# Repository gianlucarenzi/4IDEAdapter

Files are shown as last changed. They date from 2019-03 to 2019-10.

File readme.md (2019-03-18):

# Amiga 4 IDE Hard Parallel ATA Adapter
Created by Gianluca Renzi (C) 2019
E-Mail: <icjtqr@gmail.com>
<gianlucarenzi@eurek.it>

# What is it?
It is a simple but powerful adapter to use internally in any Amiga 1200 or Amiga 600 Computer installed in a tower-like case!
It must be connected to the IDE 44-pin interface on the motherboard to drive up to 4 ATA/ATAPI devices like Hard Drives, DVD Rom Drives and compatible drives.

This project follow the same DIY project in Aminet (search 4IDE in docs/hw) or simply check out here:

[Aminet 4IDE Readme](Aminet-4IDE/4IDE.readme)

# Software
[Aminet IDE97 Driver](http://aminet.net/driver/media/IDEfix97.lha)

[Aminet IDE97 Turbo Driver](http://aminet.net/driver/media/IDEfixTURBO.lha)

[Aminet IDE97 Patches](http://aminet.net/driver/media/IDEFix_patches.lha)

# Hardware Point-Of-View
This board has three indipendent activity leds, one for each channel. Moreover the activity leds are merged together in the motherboard so the HDD led nearby the floppy connector can be used as the only activity led.

# TODO
May be it can be useful to add a 90-degrees rise connector if the system has some sort of bus board, just to let this board flat as the motherboard.

# Images
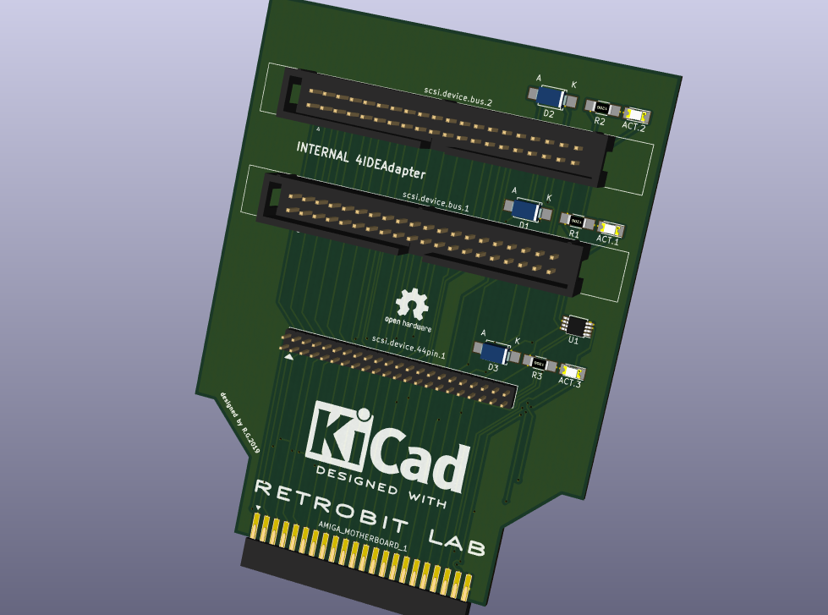
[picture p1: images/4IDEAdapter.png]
Board Overall

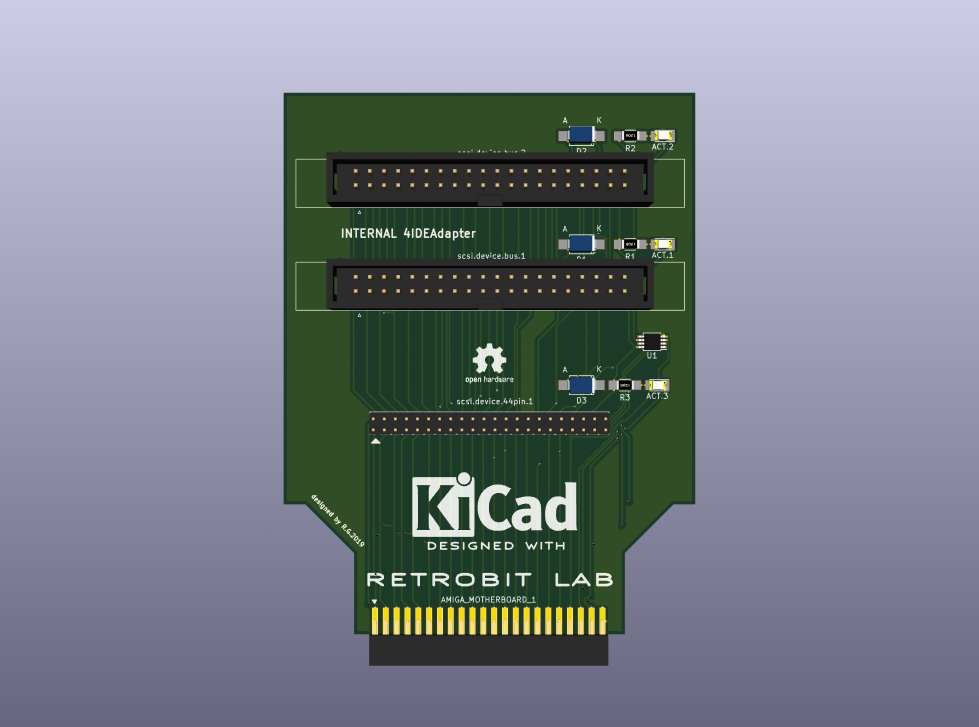
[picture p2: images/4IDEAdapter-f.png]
Board Front

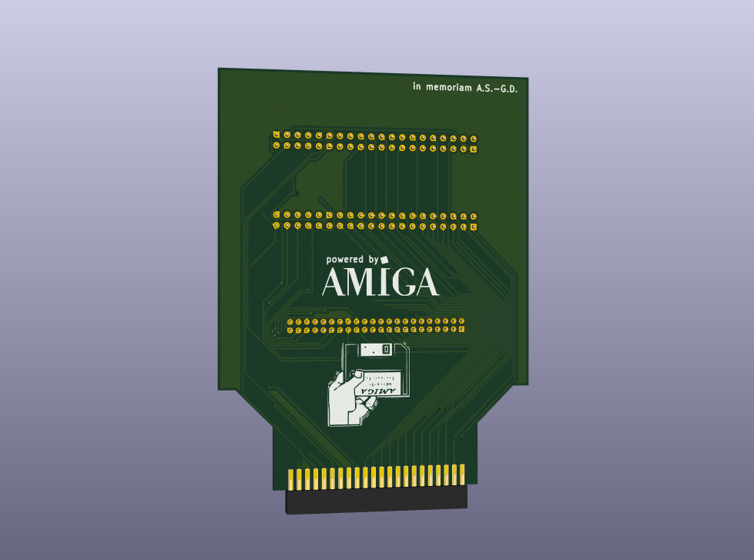
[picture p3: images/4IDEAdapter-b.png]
Board Back


# Whats changed?
V2.2 Added Aminet Stuff

# Licence
This entire project is available under the GNU General Public License v3 licence.
See licence.txt for more details.

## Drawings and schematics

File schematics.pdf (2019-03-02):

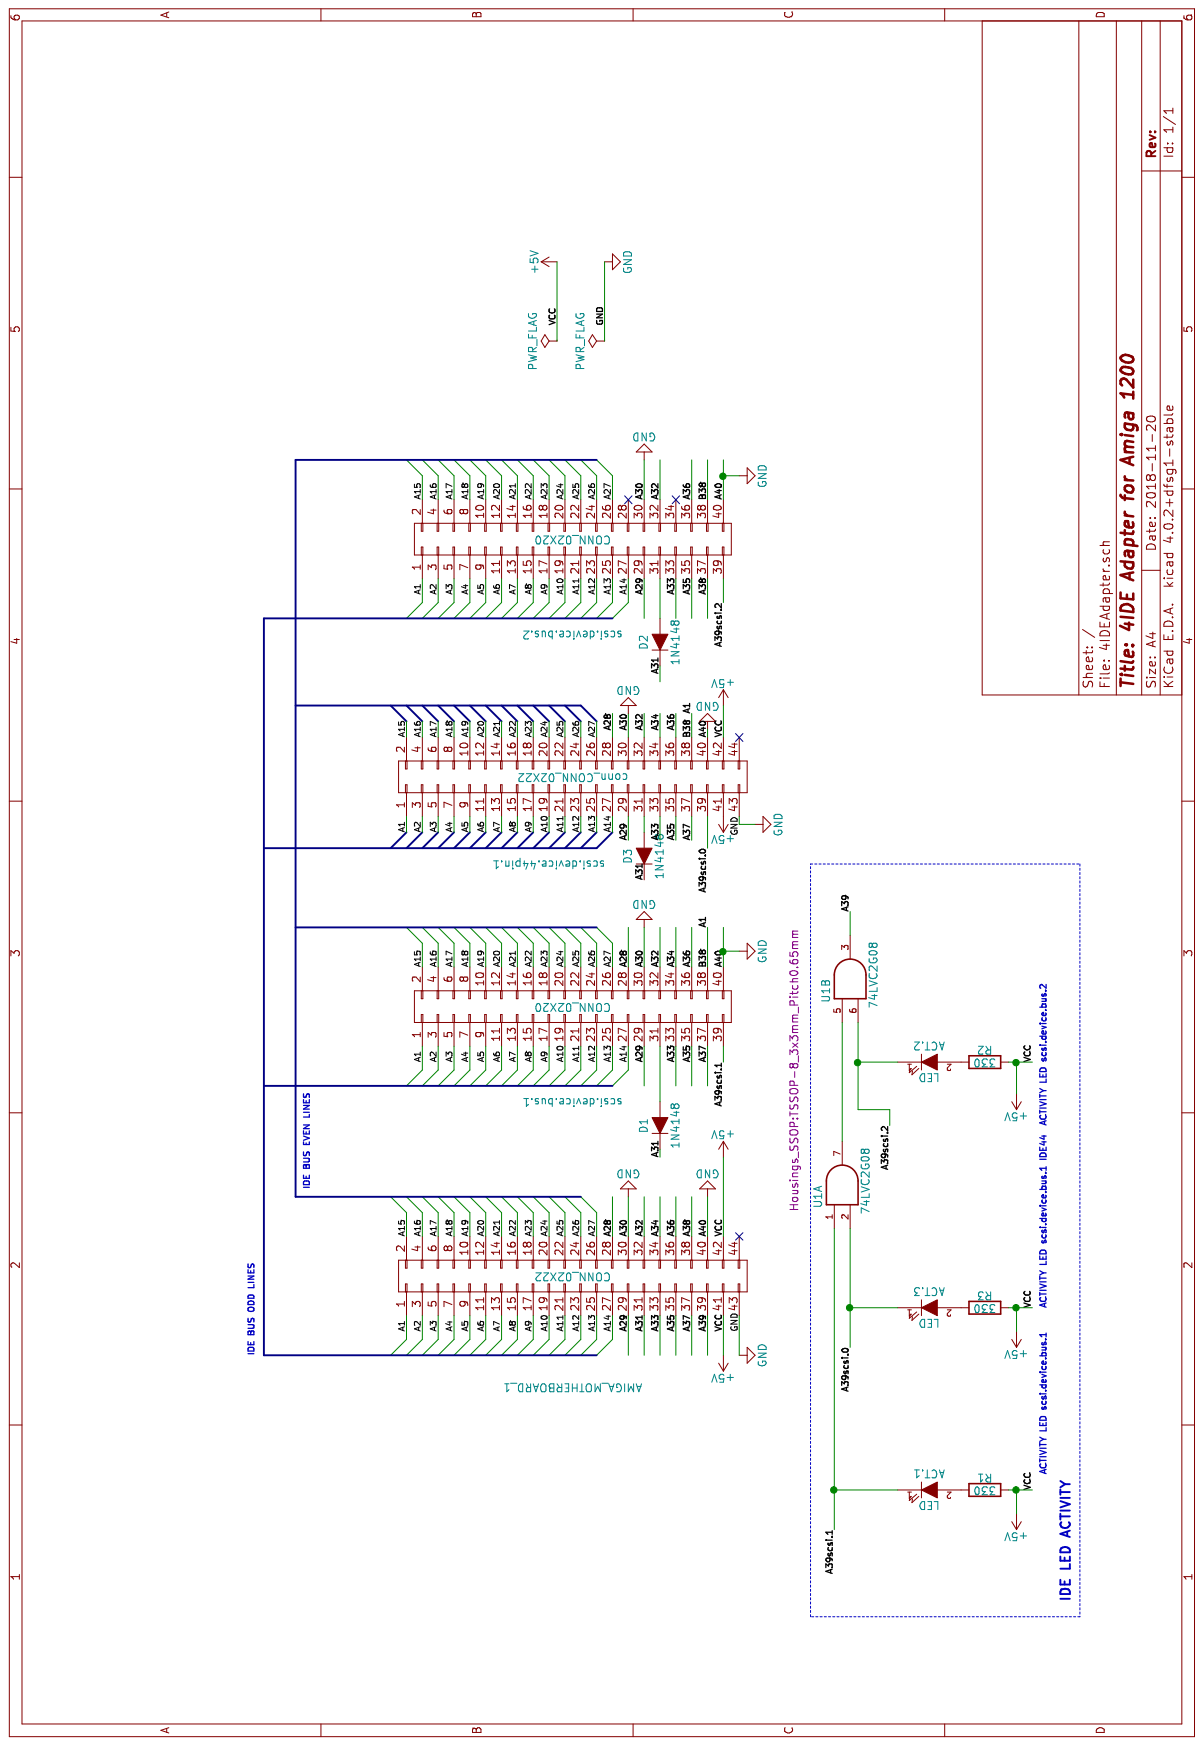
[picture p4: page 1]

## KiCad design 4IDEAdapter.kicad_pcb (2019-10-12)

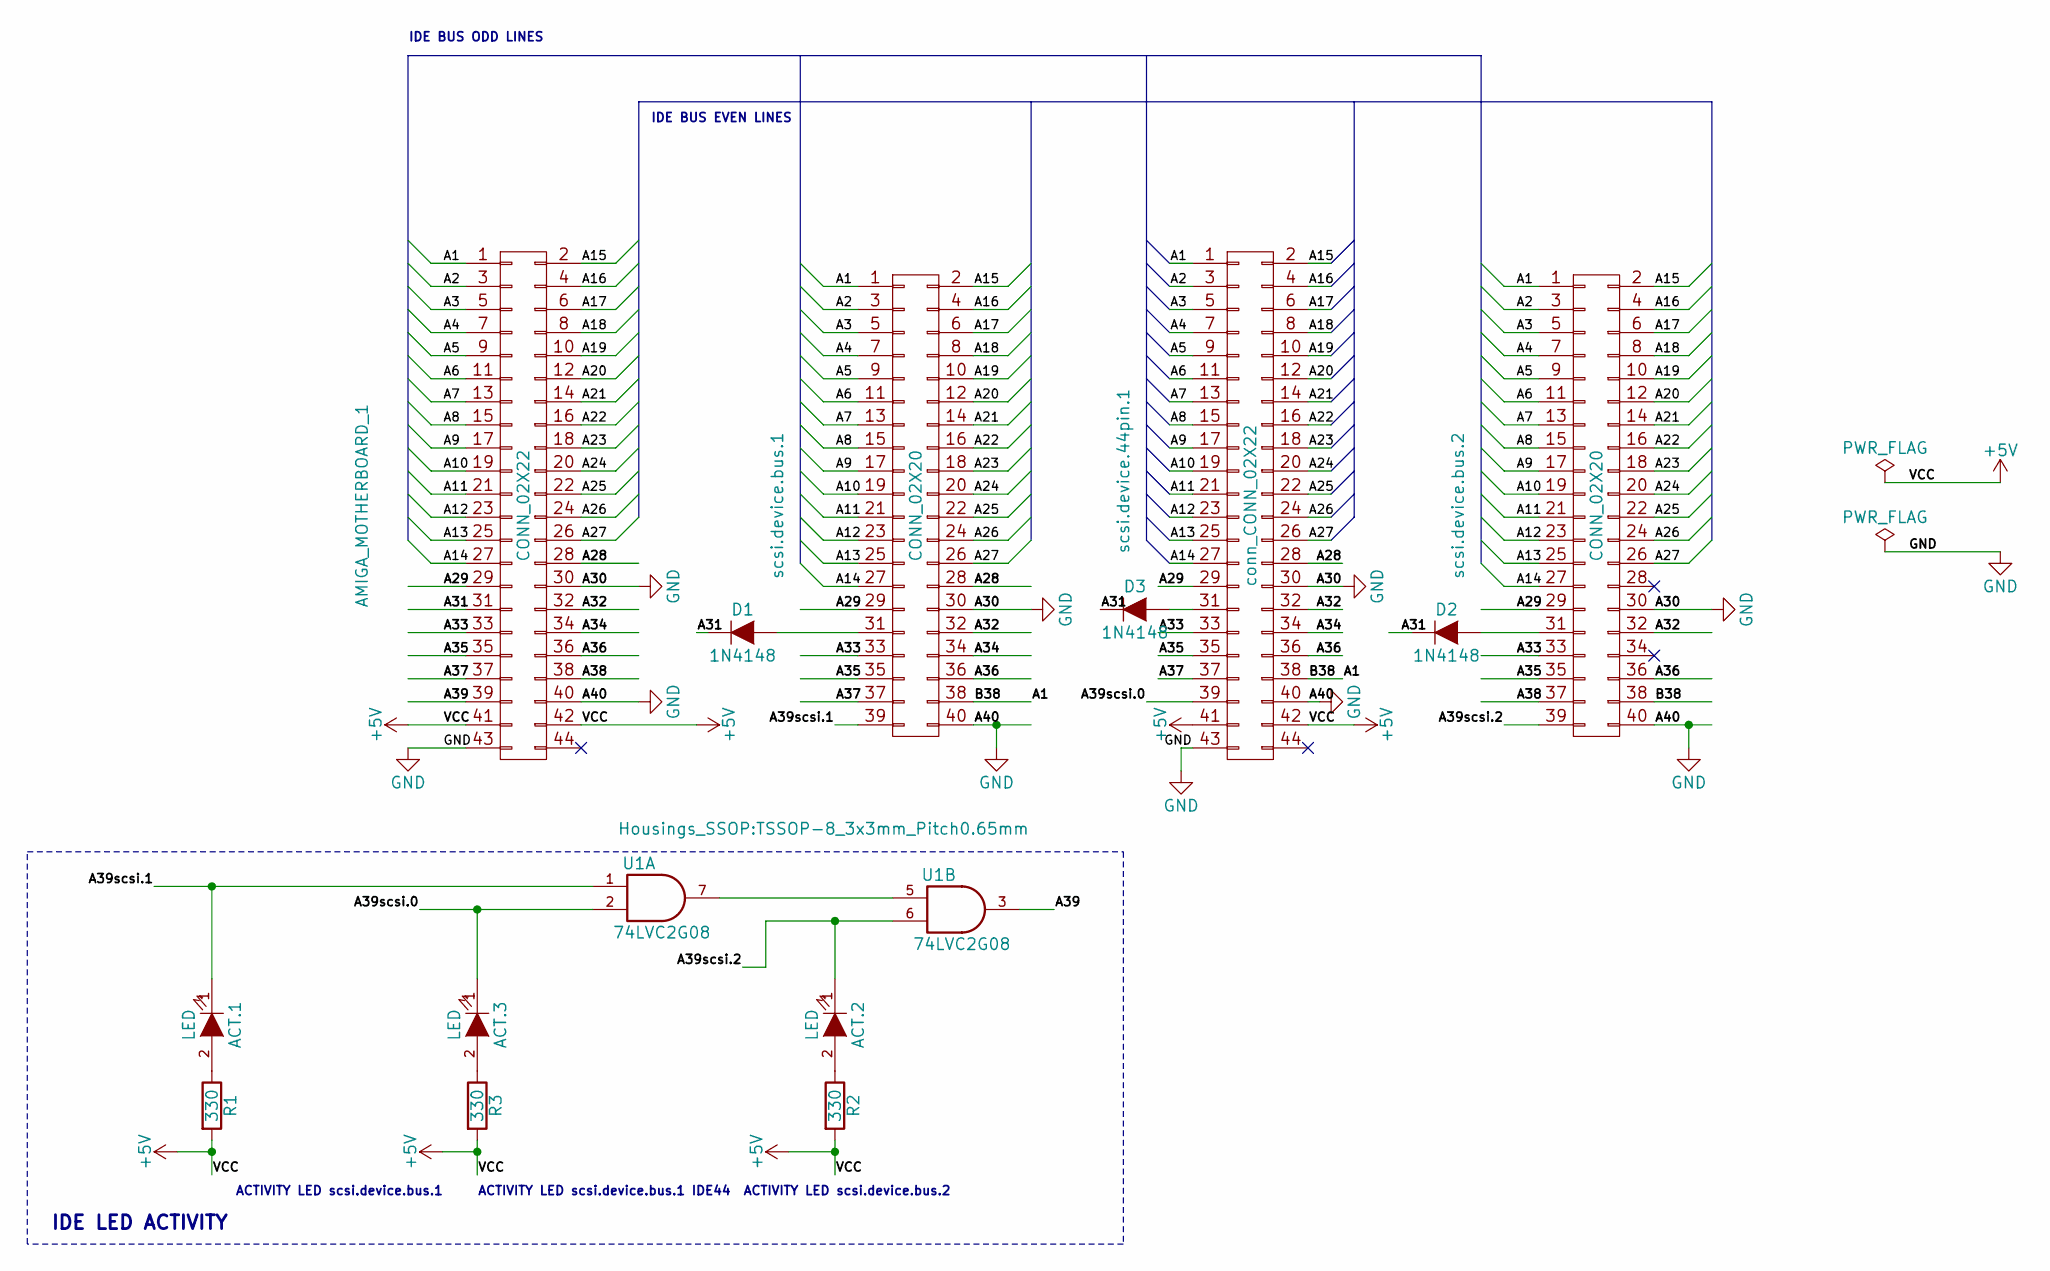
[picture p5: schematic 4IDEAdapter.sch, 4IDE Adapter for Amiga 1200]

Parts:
ACT.1, ACT.2, ACT.3: LED; LED_1206
AMIGA_MOTHERBOARD_1: CONN_02X22; Socket_IDC_2x22_2.00mm_PCB
D1, D2, D3: 1N4148; SMA_Handsoldering
R1, R2, R3: 330; R_1206_HandSoldering
U1: 74LVC2G08; TSSOP-8_3x3mm_Pitch0.65mm
scsi.device.44pin.1: conn_CONN_02X22; PinHeader_2x22_P2.00mm_Vertical
scsi.device.bus.1, scsi.device.bus.2: CONN_02X20; IDC-Header_2x20_P2.54mm_Vertical_Lock

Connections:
+5V: AMIGA_MOTHERBOARD_1.41, AMIGA_MOTHERBOARD_1.42, R1.2, R2.2, R3.2, U1.8 (VCC), scsi.device.44pin.1.41, scsi.device.44pin.1.42
/A1: AMIGA_MOTHERBOARD_1.1, scsi.device.44pin.1.1, scsi.device.44pin.1.38, scsi.device.bus.1.1, scsi.device.bus.1.38, scsi.device.bus.2.1, scsi.device.bus.2.38
/A2: AMIGA_MOTHERBOARD_1.3, scsi.device.44pin.1.3, scsi.device.bus.1.3, scsi.device.bus.2.3
/A3: AMIGA_MOTHERBOARD_1.5, scsi.device.44pin.1.5, scsi.device.bus.1.5, scsi.device.bus.2.5
/A4: AMIGA_MOTHERBOARD_1.7, scsi.device.44pin.1.7, scsi.device.bus.1.7, scsi.device.bus.2.7
/A5: AMIGA_MOTHERBOARD_1.9, scsi.device.44pin.1.9, scsi.device.bus.1.9, scsi.device.bus.2.9
/A6: AMIGA_MOTHERBOARD_1.11, scsi.device.44pin.1.11, scsi.device.bus.1.11, scsi.device.bus.2.11
/A7: AMIGA_MOTHERBOARD_1.13, scsi.device.44pin.1.13, scsi.device.bus.1.13, scsi.device.bus.2.13
/A8: AMIGA_MOTHERBOARD_1.15, scsi.device.44pin.1.15, scsi.device.bus.1.15, scsi.device.bus.2.15
/A9: AMIGA_MOTHERBOARD_1.17, scsi.device.44pin.1.17, scsi.device.bus.1.17, scsi.device.bus.2.17
/A10: AMIGA_MOTHERBOARD_1.19, scsi.device.44pin.1.19, scsi.device.bus.1.19, scsi.device.bus.2.19
/A11: AMIGA_MOTHERBOARD_1.21, scsi.device.44pin.1.21, scsi.device.bus.1.21, scsi.device.bus.2.21
/A12: AMIGA_MOTHERBOARD_1.23, scsi.device.44pin.1.23, scsi.device.bus.1.23, scsi.device.bus.2.23
/A13: AMIGA_MOTHERBOARD_1.25, scsi.device.44pin.1.25, scsi.device.bus.1.25, scsi.device.bus.2.25
/A14: AMIGA_MOTHERBOARD_1.27, scsi.device.44pin.1.27, scsi.device.bus.1.27, scsi.device.bus.2.27
/A15: AMIGA_MOTHERBOARD_1.2, scsi.device.44pin.1.2, scsi.device.bus.1.2, scsi.device.bus.2.2
/A16: AMIGA_MOTHERBOARD_1.4, scsi.device.44pin.1.4, scsi.device.bus.1.4, scsi.device.bus.2.4
/A17: AMIGA_MOTHERBOARD_1.6, scsi.device.44pin.1.6, scsi.device.bus.1.6, scsi.device.bus.2.6
/A18: AMIGA_MOTHERBOARD_1.8, scsi.device.44pin.1.8, scsi.device.bus.1.8, scsi.device.bus.2.8
/A19: AMIGA_MOTHERBOARD_1.10, scsi.device.44pin.1.10, scsi.device.bus.1.10, scsi.device.bus.2.10
/A20: AMIGA_MOTHERBOARD_1.12, scsi.device.44pin.1.12, scsi.device.bus.1.12, scsi.device.bus.2.12
/A21: AMIGA_MOTHERBOARD_1.14, scsi.device.44pin.1.14, scsi.device.bus.1.14, scsi.device.bus.2.14
/A22: AMIGA_MOTHERBOARD_1.16, scsi.device.44pin.1.16, scsi.device.bus.1.16, scsi.device.bus.2.16
/A23: AMIGA_MOTHERBOARD_1.18, scsi.device.44pin.1.18, scsi.device.bus.1.18, scsi.device.bus.2.18
/A24: AMIGA_MOTHERBOARD_1.20, scsi.device.44pin.1.20, scsi.device.bus.1.20, scsi.device.bus.2.20
/A25: AMIGA_MOTHERBOARD_1.22, scsi.device.44pin.1.22, scsi.device.bus.1.22, scsi.device.bus.2.22
/A26: AMIGA_MOTHERBOARD_1.24, scsi.device.44pin.1.24, scsi.device.bus.1.24, scsi.device.bus.2.24
/A27: AMIGA_MOTHERBOARD_1.26, scsi.device.44pin.1.26, scsi.device.bus.1.26, scsi.device.bus.2.26
/A28: AMIGA_MOTHERBOARD_1.28, scsi.device.44pin.1.28, scsi.device.bus.1.28
/A29: AMIGA_MOTHERBOARD_1.29, scsi.device.44pin.1.29, scsi.device.bus.1.29, scsi.device.bus.2.29
/A31: AMIGA_MOTHERBOARD_1.31, D1.1 (K), D2.1 (K), D3.1 (K)
/A32: AMIGA_MOTHERBOARD_1.32, scsi.device.44pin.1.32, scsi.device.bus.1.32, scsi.device.bus.2.32
/A33: AMIGA_MOTHERBOARD_1.33, scsi.device.44pin.1.33, scsi.device.bus.1.33, scsi.device.bus.2.33
/A34: AMIGA_MOTHERBOARD_1.34, scsi.device.44pin.1.34, scsi.device.bus.1.34
/A35: AMIGA_MOTHERBOARD_1.35, scsi.device.44pin.1.35, scsi.device.bus.1.35, scsi.device.bus.2.35
/A36: AMIGA_MOTHERBOARD_1.36, scsi.device.44pin.1.36, scsi.device.bus.1.36, scsi.device.bus.2.36
/A37: AMIGA_MOTHERBOARD_1.37, scsi.device.44pin.1.37, scsi.device.bus.1.37
/A38: AMIGA_MOTHERBOARD_1.38, scsi.device.bus.2.37
/A39: AMIGA_MOTHERBOARD_1.39, U1.3
/A39scsi.0: ACT.3.1 (K), U1.2, scsi.device.44pin.1.39
/A39scsi.1: ACT.1.1 (K), U1.1, scsi.device.bus.1.39
/A39scsi.2: ACT.2.1 (K), U1.6, scsi.device.bus.2.39
GND: AMIGA_MOTHERBOARD_1.30, AMIGA_MOTHERBOARD_1.40, AMIGA_MOTHERBOARD_1.43, U1.4 (GND), scsi.device.44pin.1.30, scsi.device.44pin.1.40, scsi.device.44pin.1.43, scsi.device.bus.1.30, scsi.device.bus.1.40, scsi.device.bus.2.30, scsi.device.bus.2.40
unnamed: ACT.1.2 (A), R1.1
unnamed: ACT.2.2 (A), R2.1
unnamed: ACT.3.2 (A), R3.1
unnamed: D1.2 (A), scsi.device.bus.1.31
unnamed: D2.2 (A), scsi.device.bus.2.31
unnamed: D3.2 (A), scsi.device.44pin.1.31
unnamed: U1.5, U1.7

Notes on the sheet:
IDE BUS ODD LINES
IDE BUS EVEN LINES
ACTIVITY LED scsi.device.bus.1
ACTIVITY LED scsi.device.bus.2
ACTIVITY LED scsi.device.bus.1 IDE44
IDE LED ACTIVITY

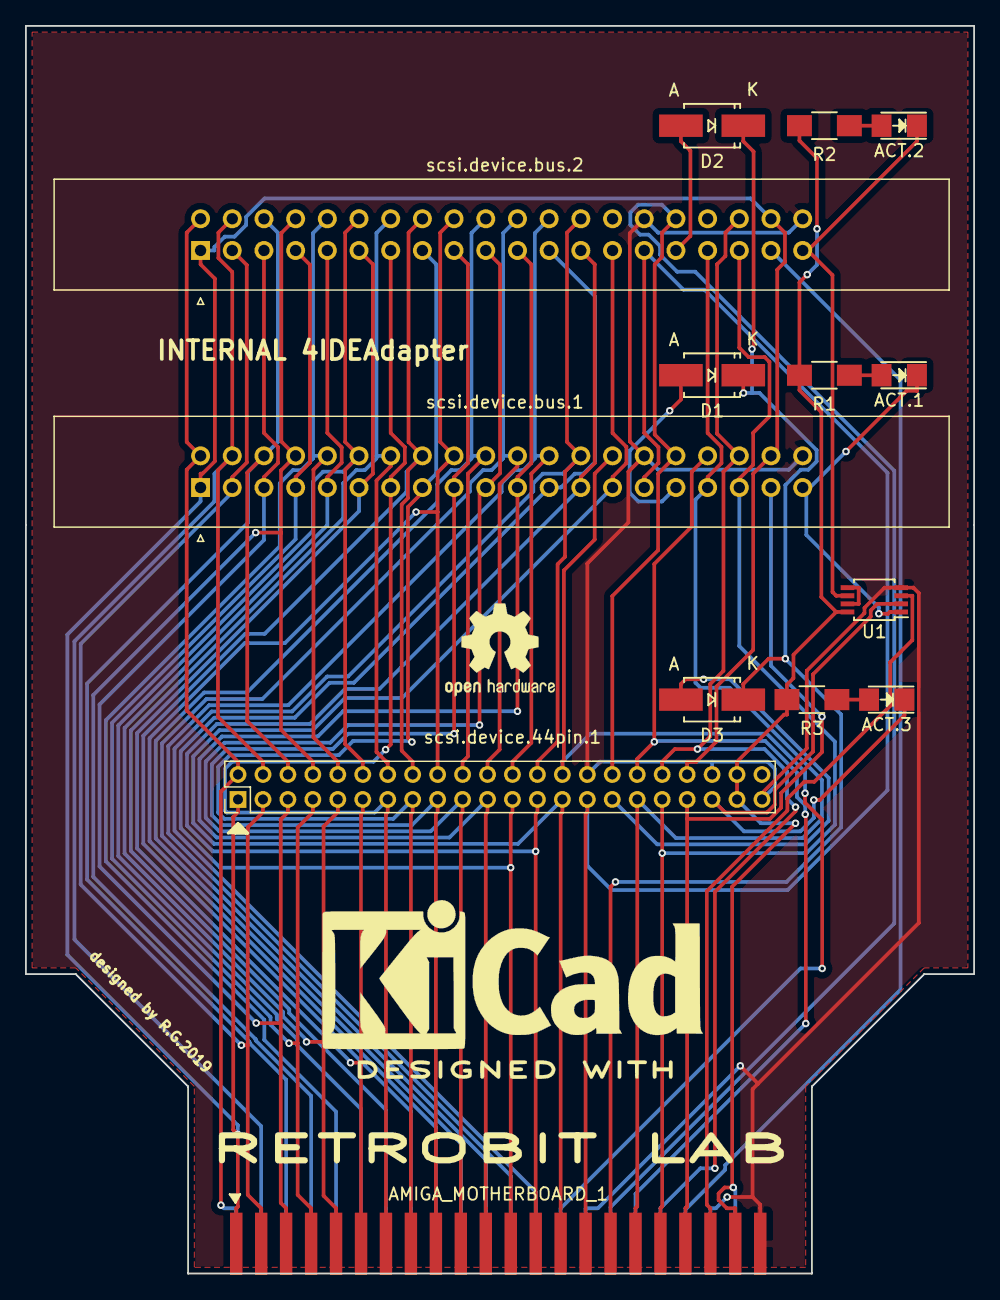
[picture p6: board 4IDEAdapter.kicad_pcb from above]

Board: 2 copper layers, 76.0 x 100.0 mm, 15 parts (0 on the bottom side), 50 nets.

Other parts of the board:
WBLOGO: KiCad-Logo2_12mm_SilkScreen

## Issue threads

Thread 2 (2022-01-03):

Gerbers without board outline

seb132, 2022-01-03:
Hello,
Great project but the board outline is not in the production file and we can't make a PCB without going back to the KiCAD source...
Have you included it? PS: I'm not using KiCAD myself but I can ask a friend to look at it...
Oh, and yes: the 90 degrees connector would be great too... :)
Seb

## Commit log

2019-03-01 first import into GitHub
    [4IDEAdapter-2019-02-04-00-21-28.sch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]
2019-03-01 added another IDE 44 pin port scsi.device.0 in parallel. ONE at TIME
    [4IDEAdapter.dsn]
2019-03-01 added a second ide port 44 pin
    [4IDEAdapter-B.Cu.gbl, 4IDEAdapter-B.Mask.gbs, 4IDEAdapter-B.Paste.gbp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]
2019-03-01 added schematics and rules for FreeRouting
2019-03-02 Updated connectors
    The IDE44 pin connector was wrong. Due to the complexity of having 3
    connectors on board the size of the board need to be increased. Now it
    is almost like a Credit Card Size. It needs an Amiga 1200 or Amiga 600
    placed into a TowerCase and *NOT TOO NEAR* to the bottom of the case...
    But if you need a 4 devices connected, for sure the default case has not
    accomplishes that!
    [4IDEAdapter-B.Cu.gbl, 4IDEAdapter-B.Mask.gbs, 4IDEAdapter-B.Paste.gbp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]
2019-03-02 added activity led management
    [4IDEAdapter-B.Cu.gbl, 4IDEAdapter-B.Mask.gbs, 4IDEAdapter-B.Paste.gbp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]
2019-03-18 Added Aminet driver links
2019-10-12 Modified silkscreen
    [4IDEAdapter-B.Cu.gbl, 4IDEAdapter-B.Mask.gbs, 4IDEAdapter-B.Paste.gbp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]
